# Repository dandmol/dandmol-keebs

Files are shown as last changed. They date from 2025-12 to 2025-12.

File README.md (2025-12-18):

# dandmol-keebs
Handwired mechanical keyboards, custom PCBs and QMK/Vial firmware.

## es Castellano
### ¿Qué es este repo?
Este repositorio recoge mis proyectos de teclados mecánicos:
- **Teclados handwired** (matriz cableada, controladoras tipo RP2040, Pro Micro, etc.).
- Proyectos con PCBs propias o montadas sobre placas existentes.
- Firmware: QMK, Vial (y en el futuro quizá KMK u otros).
- Layouts, esquemas y notas para documentar cada build.

## 🇪🇺 Euskaraz
### Zer da repo hau?
Repo honek nire **teklatu mekanikoen proiektuak** biltzen ditu:

- **Handwired** teklatuak (matrizea kablez, kontrolagailu tipo RP2040, Pro Micro, etab.).
- **PCB propioak** edo kanpoko plaken gaineko muntaiak.
- **Firmwarea**: QMK, Vial (eta etorkizunean KMK edo antzekoak, behar bada).
- Layout, eskema eta oharrak, etorkizunean niretzat zein besteentzako erreferentzia izan daitezen

## en English
### What is this repo?
This repository collects my mechanical keyboard projects:
- **Handwired keyboards** (wired matrix, controllers like RP2040, Pro Micro, etc.).
- Custom **PCBs** or builds based on existing boards.
- **Firmware**: QMK, Vial (and maybe KMK or others in the future).
- Layouts, wiring diagrams and notes for each build.

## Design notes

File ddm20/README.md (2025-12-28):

# ddm20 – Numpad 5×4 con RP2040-Zero



`ddm20` es un numpad / macropad ortolineal de 5 filas × 4 columnas, basado en un **RP2040-Zero**, cableado a mano (*handwired*) y pensado para usarse como keypad numérico principal con una segunda capa de navegación y multimedia.

El repositorio incluye:

- Configuración completa para **QMK** (`keyboard.json`, `keymap.c`, `config.h`, `rules.mk`).
- Diseño de **carcasa imprimible en 3D** en la carpeta `case/`.
- Esquema de cableado (filas, columnas, diodos) y materiales utilizados.

---

## Especificaciones de hardware

- **Controlador**: RP2040-Zero (clon chino tipo Pro Micro RP2040).
- **Distribución**: ortho 5×4.
- **Matriz**: 5 filas × 4 columnas.
- **Switches**: Outemu **Tactile Maple Leaf**, 3 pines (en mi montaje he usado 16 unidades).
- **Diodos**: 1N4148 DO-35, **uno por tecla**.
- **LED indicador de capa**: 1 × LED (3 mm) + resistencia (330 Ω) conectado a `GP1` (se enciende cuando la capa 1 está activa).
- **Cableado**: cable de silicona **24 AWG** para filas y columnas.
- **Tornillería**: tornillos **M3 × 16 mm** para cerrar la caja.
- **Tipo de escaneado**:
  - `diode_direction`: `ROW2COL`
  - Filas y columnas definidas en `keyboard.json`.


### Asignación de pines (filas y columnas)

Cableado físico desde el RP2040-Zero:

**Filas** (de arriba a abajo, mirando el teclado desde arriba):

| Fila | Descripción | Pin RP2040 |
|---|---|---|
| F0 | Fila 1 (arriba) | `GP2` |
| F1 | Fila 2 | `GP3` |
| F2 | Fila 3 | `GP4` |
| F3 | Fila 4 | `GP5` |
| F4 | Fila 5 (abajo) | `GP6` |

**Columnas** (de izquierda a derecha, con diodos):

Cada tecla está cableada como:

```text
FILA → switch → diodo (1N4148) → COLUMNA
```

| Columna | Descripción | Pin RP2040 |
|---|---|---|
| C0 | Columna 1 (izquierda)  | `GP9` |
| C1 | Columna 2 | `GP10` |
| C2 | Columna 3 | `GP11` |
| C3 | Columna 4 (derecha) | `GP12` |

### Diodos

- **Modelo**: 1N4148 DO-35.
- **Montaje**: un diodo por tecla, todos con la misma orientación.
- Todos los diodos de una columna se unen por el lado de columna (tras el diodo) a su cable de columna correspondiente.

---

## Carcasa e impresión 3D

En la carpeta `case/` se incluyen los ficheros STL para imprimir la carcasa y la estructura del teclado.

El diseño base está tomado de:

**4x5 Macro Pad v3 (nice!nano version)** – MakerWorld

y adaptado para montar el RP2040-Zero y el cableado handwired de este proyecto:

https://makerworld.com/en/models/1730477-4x5-macro-pad-v3-nice-nano-version

---

## Configuración de QMK

### keyboard.json

Configuración principal del teclado:

- **Procesador**: RP2040
- **Bootloader**: rp2040

**Matriz**:

```json
"matrix_pins": {
    "cols": ["GP9", "GP10", "GP11", "GP12"],
    "rows": ["GP2", "GP3", "GP4", "GP5", "GP6"]
}
```

**Dirección de los diodos**:

```json
"diode_direction": "ROW2COL"
```

### rules.mk

```make
# Para no heredar el "Pro Micro RP2040" por defecto
BOARD = GENERIC_RP_RP2040

# Para sacar consola de depuración (muy útil para ver matriz)
CONSOLE_ENABLE = yes
COMMAND_ENABLE = yes

# Habilitar combos (para el combo de bootloader)
COMBO_ENABLE = yes
```

- `BOARD = GENERIC_RP_RP2040` fuerza el uso del board genérico de RP2040.
- `CONSOLE_ENABLE = yes` permite usar `qmk console` para ver la matriz y mensajes de debug.
- `COMMAND_ENABLE = yes` habilita comandos especiales de QMK (Magic/Command).
- `COMBO_ENABLE = yes` activa el soporte de combos (usados para entrar en bootloader con varias teclas).

### config.h

Fragmento relevante para LED y combos:

```c
// LED indicador de capa en GP1
#define LED_LAYER_PIN GP1

#ifdef COMBO_ENABLE
#    define COMBO_TERM 100    // Ventana de tiempo (ms) para detectar el combo
#endif
```

---

## Keymap

En `keymap.c` se define, entre otras cosas:

```c
// Mute global del micro en Windows 11: Win + Alt + K
#define KC_WIN_MIC_MUTE LAG(KC_K)
```

### Capa 0 – Numpad (por defecto)

```c
[0] = LAYOUT_ortho_5x4(
    TG(1),   KC_CALC, KC_PSLS, KC_PAST,
    KC_P7,   KC_P8,   KC_P9,   KC_PMNS,
    KC_P4,   KC_P5,   KC_P6,   KC_PPLS,
    KC_P1,   KC_P2,   KC_P3,   S(KC_0),   // "=" en distribución ES → Shift + 0
    KC_PENT, KC_P0,   KC_PDOT, KC_PENT
),
```

**Funciones destacadas**:

- `TG(1)`: activa/desactiva la capa 1.
- `KC_CALC`: abre la calculadora de Windows.
- Números y operaciones estándar de un keypad numérico.
- `S(KC_0)`: envía Shift + 0, que en distribución española escribe `=` (así se consigue la tecla =).

### Capa 1 – Multimedia y navegación

Versión final de la distribución:

```c
[1] = LAYOUT_ortho_5x4(
    TG(1),           KC_HOME,        KC_PGUP,        KC_VOLD,
    KC_WIN_MIC_MUTE, KC_END,         KC_PGDN,        KC_VOLU,
    XXXXXXX,         KC_BRID,        KC_BRIU,        KC_MUTE,
    KC_MPRV,         KC_UP,          KC_MNXT,        KC_MPLY,
    KC_LEFT,         KC_DOWN,        KC_RGHT,        KC_ENT
)
```

**Resumen de funciones**:

**Fila 0**:
- `TG(1)`: alterna la capa 1.
- `KC_HOME`, `KC_PGUP`, `KC_VOLD`: inicio de línea, página arriba, volumen abajo.

**Fila 1**:
- `KC_WIN_MIC_MUTE`: mute global de micro en Windows 11 (Win + Alt + K).
- `KC_END`, `KC_PGDN`, `KC_VOLU`: fin de línea, página abajo, volumen arriba.

**Fila 2**:
- `KC_BRID`, `KC_BRIU`: brillo abajo/arriba (en sistemas que soporten estos keycodes).
- `KC_MUTE`: mute general.

**Fila 3**:
- `KC_MPRV`, `KC_MNXT`, `KC_MPLY`: pista anterior, siguiente y Play/Pause (Spotify, YouTube, etc. vía teclas multimedia del sistema).
- `KC_UP`: cursor arriba.

**Fila 4**:
- `KC_LEFT`, `KC_DOWN`, `KC_RGHT`, `KC_ENT`: cursores y Enter en la misma posición que en la capa numérica.

---

## Combo para entrar en bootloader

Además de las formas habituales de entrar en bootloader del RP2040-Zero, este teclado define un combo en la capa 0:

**Pulsar a la vez**: `5` + `7` + `*` del keypad numérico  
→ envía `QK_BOOT` y el teclado entra en modo bootloader.

**Implementación en `keymap.c`**:

```c
// Identificadores de combos
enum custom_combos {
    BOOT_COMBO,
};

// Combo para entrar en bootloader: pulsar 5 + 7 + * (KC_P5, KC_P7, KC_PAST)
const uint16_t PROGMEM boot_combo[] = { KC_P5, KC_P7, KC_PAST, COMBO_END };

combo_t key_combos[] = {
    [BOOT_COMBO] = COMBO(boot_combo, QK_BOOT),
};
```

El comportamiento del combo está controlado por `COMBO_TERM` en `config.h` (100 ms por defecto).

---

## Indicador de capa por LED

El teclado incluye un LED conectado a `GP1` definido como:

```c
#define LED_LAYER_PIN GP1
```

En `keyboard_post_init_user` se configura el pin como salida y se apaga el LED al inicio:

```c
void keyboard_post_init_user(void) {
    debug_enable = true;
    debug_matrix = true;

    // Configurar el pin del LED de capa como salida y apagarlo
    setPinOutput(LED_LAYER_PIN);
    writePin(LED_LAYER_PIN, 0);

    // Forzar Num Lock activo al arrancar
    if (!host_keyboard_led_state().num_lock) {
        tap_code(KC_NUM_LOCK);
    }
}
```

Y en `layer_state_set_user` se controla el estado del LED según la capa activa:

```c
layer_state_t layer_state_set_user(layer_state_t state) {
    bool layer1_on = layer_state_cmp(state, 1);
    writePin(LED_LAYER_PIN, layer1_on ? 1 : 0);
    return state;
}
```

- LED **apagado** → solo capa 0 activa.
- LED **encendido** → capa 1 activa (media / navegación).

---

## Num Lock automático al arrancar

En `keyboard_post_init_user` se fuerza Num Lock activo al iniciar el teclado:

```c
void keyboard_post_init_user(void) {
    debug_enable = true;
    debug_matrix = true;    
    
    // Forzar Num Lock activo al arrancar
    if (!host_keyboard_led_state().num_lock) {
        tap_code(KC_NUM_LOCK);
    }
}
```

Esto evita tener que pulsar Num Lock manualmente al conectar el numpad en portátiles sin keypad integrado.

---

## Compilación y flasheo

### Compilar con QMK (recomendado)

Desde la raíz de `qmk_firmware`:

```bash
qmk compile -kb ddm20 -km default
```

Esto genera un `.uf2` en la carpeta `.build/`.

### Flasheo en RP2040-Zero

1. Mantener pulsado el botón **BOOT** del RP2040-Zero mientras se conecta al USB.
2. Aparece una unidad de almacenamiento tipo `RPI-RP2` / similar.
3. Copiar el fichero `.uf2` generado a esa unidad.
4. El dispositivo se reinicia automáticamente con el nuevo firmware.

---

## Depuración de la matriz

Con `CONSOLE_ENABLE = yes` y:

```c
void keyboard_post_init_user(void) {
    debug_enable = true;
    debug_matrix = true;
    ...
}
```

se puede ver el estado de la matriz con:

```bash
qmk console
```

Esto fue especialmente útil durante el montaje para verificar:

- Continuidad de filas y columnas.
- Dirección correcta de diodos.
- Detección individual de cada tecla (fila + columna).

---

## Mantenimiento y extensiones

El keymap actual está pensado como numpad principal con una segunda capa de navegación y multimedia.

Es sencillo modificar `keymap.c` para:

- Añadir macros (por ejemplo, combinaciones de atajos de desarrollo).
- Cambiar la tecla de `KC_CALC` por otra función.
- Ajustar la capa 1 a otro flujo de trabajo (edición de vídeo, atajos de IDE, etc.).

---

## Autor

**Keyboard Maintainer**: Daniel Durán ([@dandmol](https://github.com/dandmol))

---

## Licencia

El firmware y la configuración de QMK (`keyboard.json`, `keymap.c`, `config.h`, `rules.mk`, etc.) son un derivado de QMK y se distribuyen bajo licencia **GPL-2.0-or-later**.

La documentación de este repositorio (README, texto explicativo, etc.) y las fotos del montaje se publican bajo licencia **Creative Commons Atribución 4.0 (CC BY 4.0)**, salvo que se indique lo contrario.

Los modelos 3D de la carpeta `case/` son una adaptación del modelo "4x5 Macro Pad v3 (nice!nano version)" publicado en MakerWorld bajo licencia **Creative Commons Atribución–No Comercial (CC BY-NC)**.  
Esta adaptación mantiene la misma condición de uso no comercial: no se permite el uso comercial de la carcasa ni de sus derivados.

Cualquier modificación, PR o fork para añadir más layouts, variantes de carcasa o mejoras es bienvenida, siempre que respete las licencias anteriores.

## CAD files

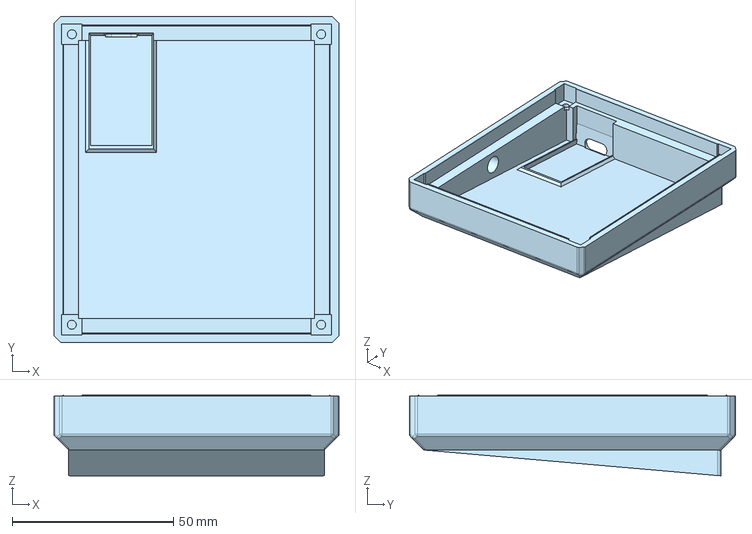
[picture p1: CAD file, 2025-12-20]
ddm20/case/4x5+macro+pad+v3+-+base.step
88.3 x 101.0 x 25.0 mm

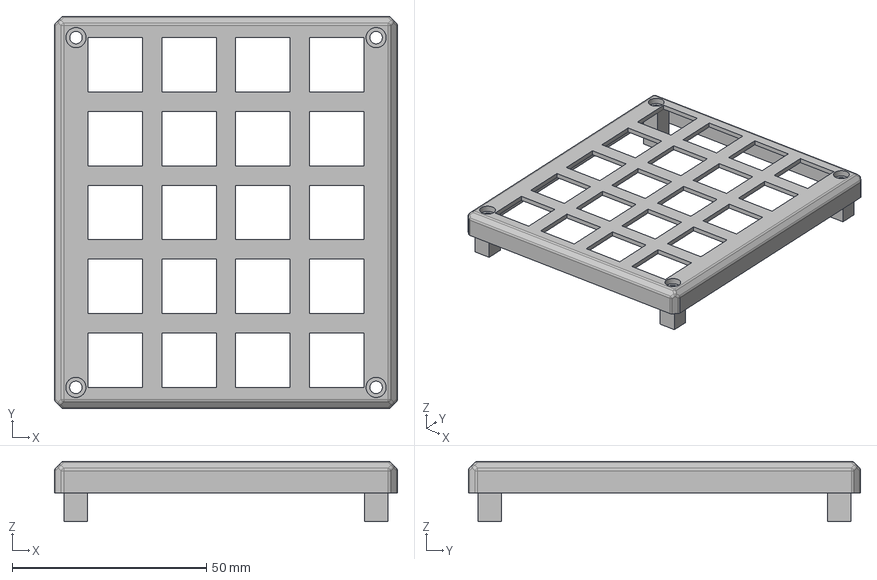
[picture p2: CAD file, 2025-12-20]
ddm20/case/4x5+macro+pad+v3+-+plate.step
88.3 x 101.0 x 15.5 mm

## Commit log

2025-12-22 Add README for ddm5x4 numpad project
    Added detailed documentation for the ddm5x4 numpad project, including specifications, wiring, QMK configuration, and usage instructions.
2025-12-28 Document LED layer indicator in README
    Added section for LED layer indicator functionality.
